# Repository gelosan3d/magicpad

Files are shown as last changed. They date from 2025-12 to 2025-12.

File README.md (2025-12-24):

# Angelos' MagicPad

### Renders + Workplace Screenshots 
Fusion_Case_Pretty
Case_Pretty_1


---

### Inspiration: 
I got my main inspiration from existing streaming decks and macropads such as the Elgado Streakdeck. I really liked the customisability but always though that the buttons were very tacky when pressed and I didn't particularly like the lack of a knob in some models

### BOM:
- 1x XIAO RP2040
- 2x SK6812MINI-E LED's 
- 2x EC11 Rotary Encoders
- 8x Cherry MX Footprint Switches
- 1x 0.91" OLED Panel
- 1x [MCP23017 IO Expander](https://item.taobao.com/item.htm?id=873700756247) (TaoBao Link)
- 3x [4.7kΩ Resistors](https://detail.tmall.com/item.htm?id=855810249338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) (TMall Link) 
- 4x [m3 5W4D Heat-set Inserts](https://www.aliexpress.us/item/2255800046543591.html)
- 4x m3x16mm Screws

#### 3D Print:
  - Top_Case.stl
  - Bottom_Case.stl

Schematic            |  PCB         |   Case
:-------------------------:|:-------------------------:|:-------------------------:|
  |   | 

### Licensing
This project falls under the MIT License (see LICENSE.md), which I chose because of how much I used all the amazing community projects and help (a ***lot*** with the code) and the support from the overall open-source community. 

This has inspired and made me want to leave my work as open source, hopefully inspiring or helping someone else in the future! 

--- 

### Thanks!!!
Many many many thanks to everyone at the Hackclub team and AMD for making this work, really amazing help and support to the whole community!

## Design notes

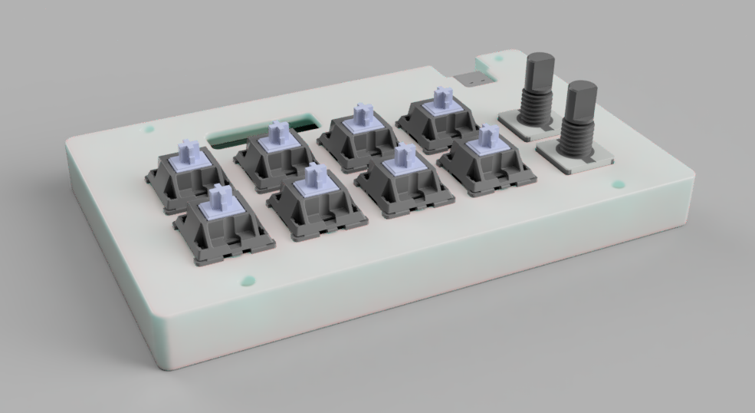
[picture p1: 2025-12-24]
CAD/Case_Pretty_1.png

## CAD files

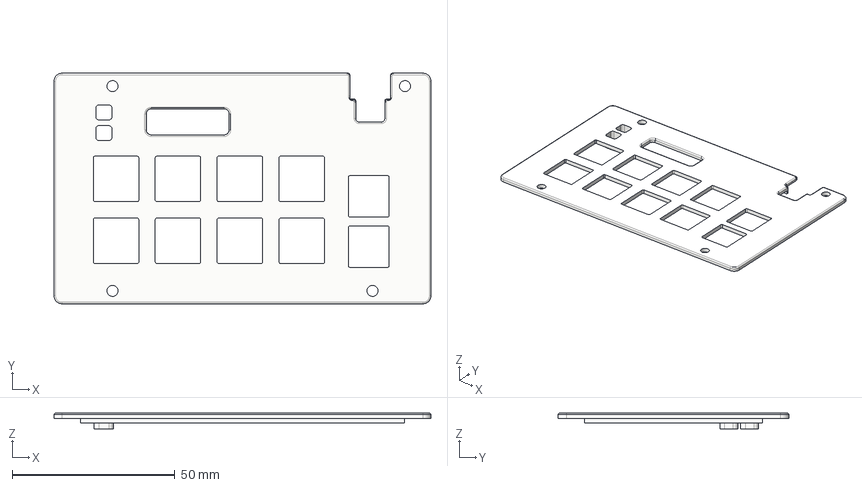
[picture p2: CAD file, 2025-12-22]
CAD/Case_Top.step
116.0 x 71.0 x 4.90 mm

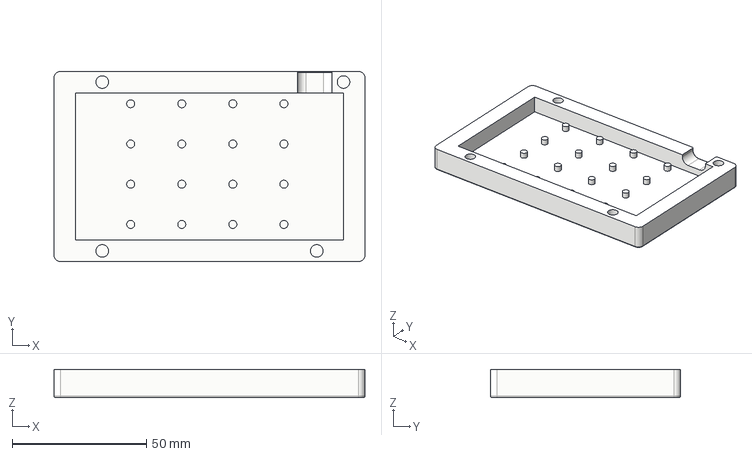
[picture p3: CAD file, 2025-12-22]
CAD/Case_Bottom.step
116.0 x 71.0 x 10.5 mm

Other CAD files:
CAD/Case_v1_Case_Bottom.f3d
CAD/Case_v1_Case_Top.f3d
CAD/Extras/Cherry_MX_Switch.f3d
CAD/Extras/LED SK6812MINI-E.f3d
CAD/Extras/Rotary_Encoder.f3d
CAD/Extras/Seeed Studio XIAO RP2040.f3d
CAD/PCB_v3.f3d

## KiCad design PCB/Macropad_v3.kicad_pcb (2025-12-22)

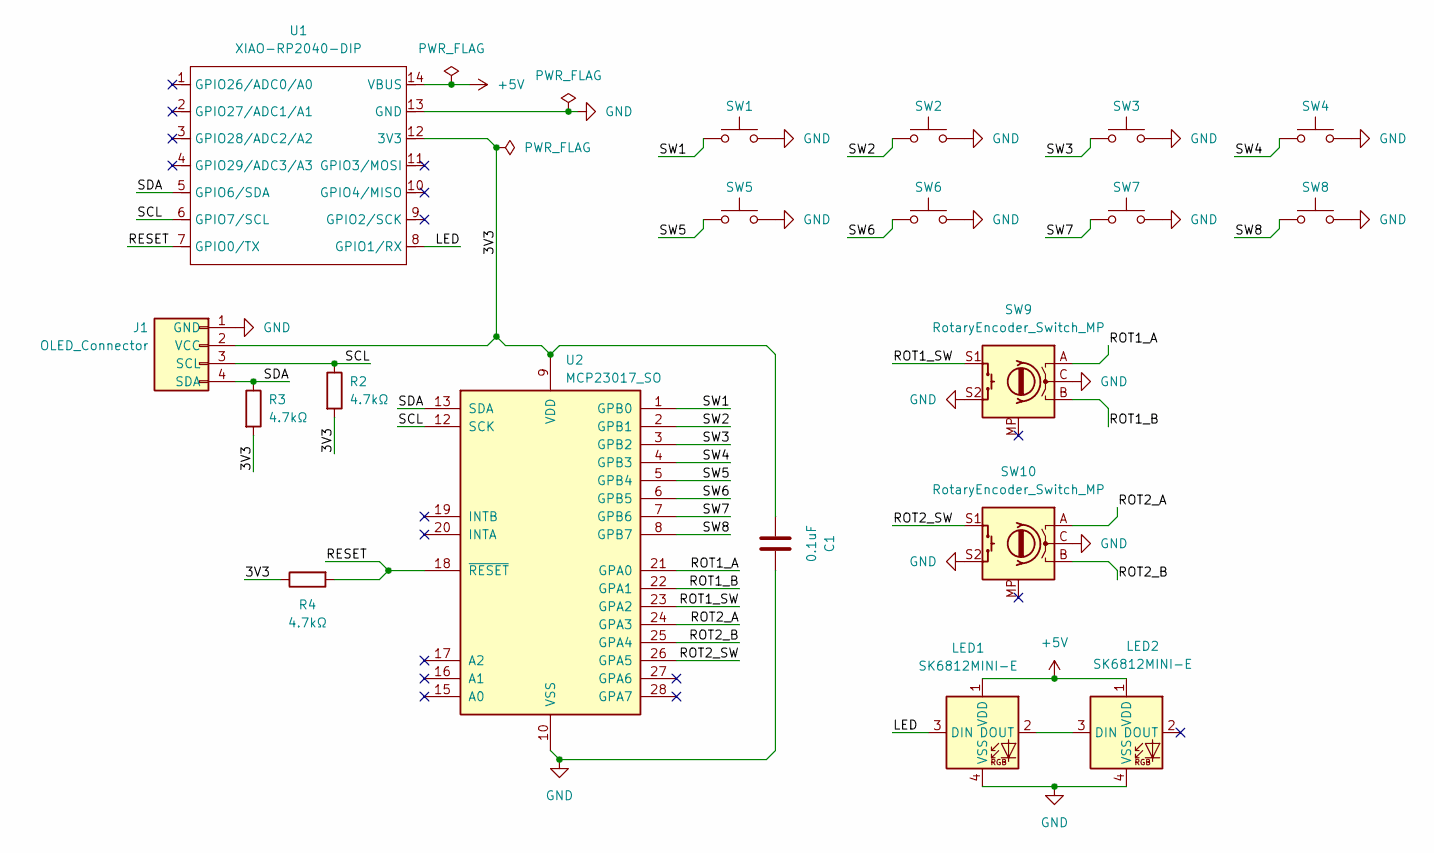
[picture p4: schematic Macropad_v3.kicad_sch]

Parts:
C1: 0.1uF; C_0603_1608Metric_Pad1.08x0.95mm_HandSolder
J1: OLED_Connector; SSD1306-0.91-OLED-4pin-128x32
LED1, LED2: SK6812MINI-E; LED_6028R
R2, R3, R4: 4.7kΩ; R_0603_1608Metric_Pad0.98x0.95mm_HandSolder
SW1, SW2, SW3, SW4, SW5, SW6, SW7, SW8: SW_Push; SW_Cherry_MX_1.00u_PCB
SW9, SW10: RotaryEncoder_Switch_MP; RotaryEncoder_Alps_EC11E-Switch_Vertical_H20mm_CircularMoun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
U1: XIAO-RP2040-DIP
U2: MCP23017_SO; SOIC-28W_7.5x17.9mm_P1.27mm

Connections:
+5V: LED1.1 (VDD), LED2.1 (VDD), U1.14 (VBUS)
/3V3: C1.1, J1.2 (VCC), R2.2, R3.2, R4.1, U1.12 (3V3), U2.9 (VDD)
/LED: LED1.3 (DIN), U1.8 (GPIO1/RX)
/RESET: R4.2, U1.7 (GPIO0/TX), U2.18 (~RESET)
/ROT1_A: SW9.A, U2.21 (GPA0)
/ROT1_B: SW9.B, U2.22 (GPA1)
/ROT1_SW: SW9.S1, U2.23 (GPA2)
/ROT2_A: SW10.A, U2.24 (GPA3)
/ROT2_B: SW10.B, U2.25 (GPA4)
/ROT2_SW: SW10.S1, U2.26 (GPA5)
/SCL: J1.3 (SCL), R2.1, U1.6 (GPIO7/SCL), U2.12 (SCK)
/SDA: J1.4 (SDA), R3.1, U1.5 (GPIO6/SDA), U2.13 (SDA)
/SW1: SW1.1, U2.1 (GPB0)
/SW2: SW2.1, U2.2 (GPB1)
/SW3: SW3.1, U2.3 (GPB2)
/SW4: SW4.1, U2.4 (GPB3)
/SW5: SW5.1, U2.5 (GPB4)
/SW6: SW6.1, U2.6 (GPB5)
/SW7: SW7.1, U2.7 (GPB6)
/SW8: SW8.1, U2.8 (GPB7)
GND: C1.2, J1.1 (GND), LED1.4 (VSS), LED2.4 (VSS), SW1.2, SW2.2, SW3.2, SW4.2, SW5.2, SW6.2, SW7.2, SW8.2, SW9.C, SW9.S2, SW10.C, SW10.S2, U1.13 (GND), U2.10 (VSS)
unnamed: LED1.2 (DOUT), LED2.3 (DIN)

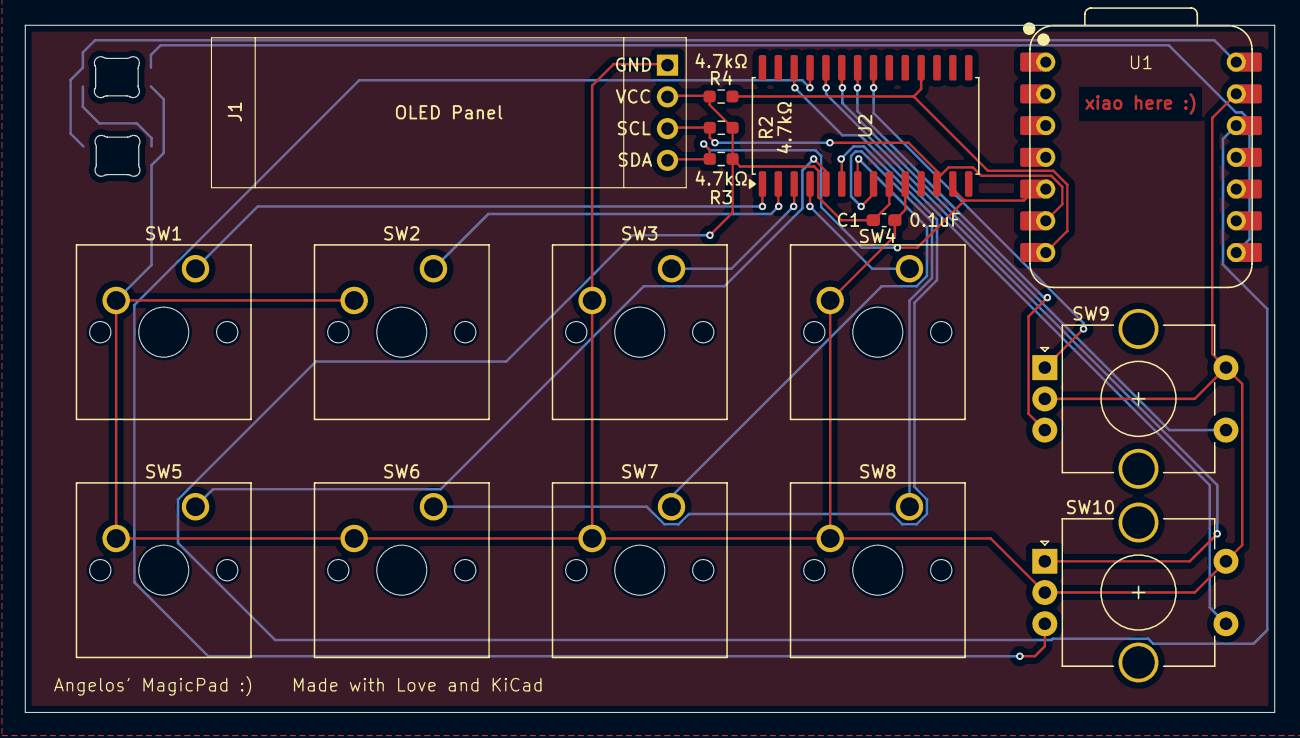
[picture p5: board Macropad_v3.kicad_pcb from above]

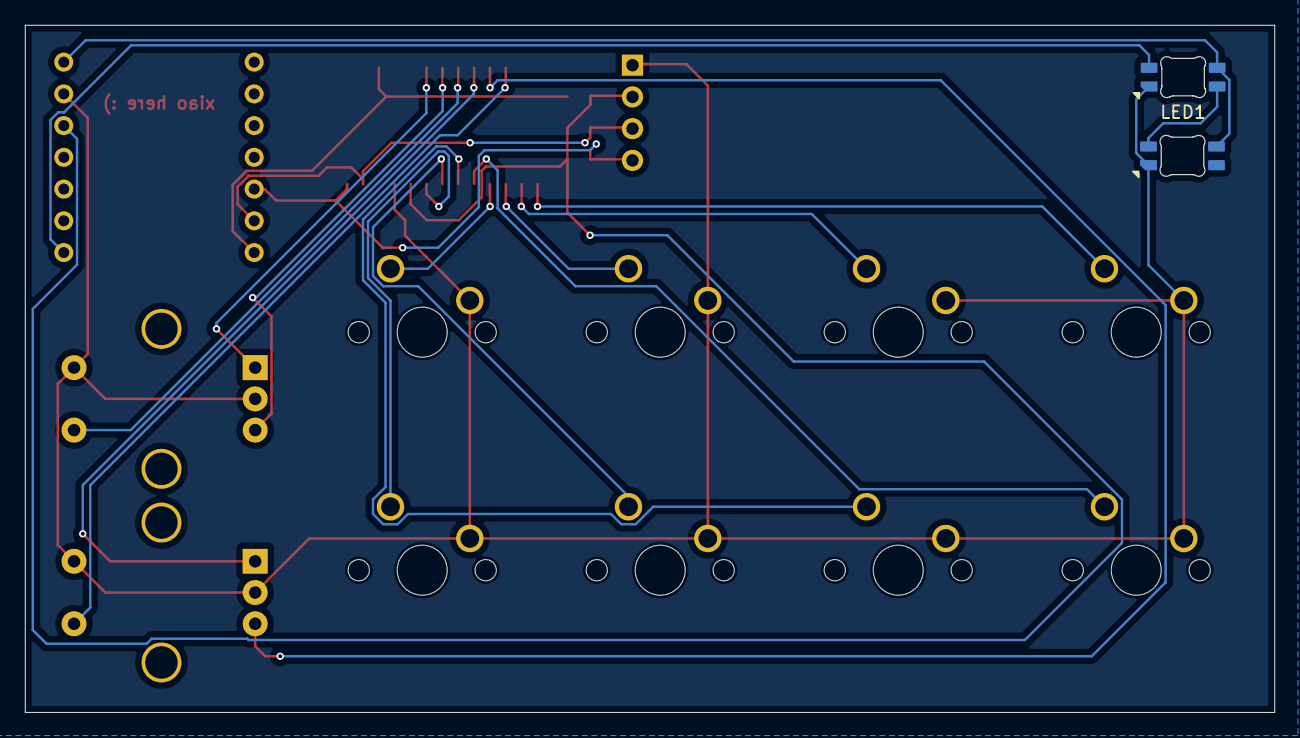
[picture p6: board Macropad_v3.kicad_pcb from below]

Board: 2 copper layers, 100.0 x 55.0 mm, 19 parts (2 on the bottom side), 22 nets.

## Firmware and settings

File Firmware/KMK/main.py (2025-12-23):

print("Starting macropad firmware")

from kmk_firmware.kmk.kmk_keyboard import KMKKeyboard
from board.pins import oled
from kmk_firmware.kmk.modules.layers import Layers
from kmk_firmware.kmk.keys import KC
keyboard = KMKKeyboard()

layers = Layers()
keyboard.modules.append(layers)
NUM_LAYERS = 8  # define number of layers, 8 is max allowed 

current_layer = 0
def encoder_layer_cycle(direction):
    global current_layer
    if direction > 0:
        current_layer = (current_layer + 1) % NUM_LAYERS
    else:
        current_layer = (current_layer - 1) % NUM_LAYERS
    keyboard.active_layers = [current_layer]


from board.pins import (
    DIRECT_PINS,
    ENC1_A, ENC1_B,
    ENC2_A, ENC2_B,
    LED_DATA,
)

from kmk_firmware.kmk.scanners import DirectPins
keyboard.matrix = DirectPins (
    pins = DIRECT_PINS,
    value_when_pressed = False
)

from kmk_firmware.kmk.modules.encoders import EncoderHandler
encoder = EncoderHandler()
encoder.pins = (
    (ENC1_A, ENC1_B),
    (ENC2_A, ENC2_B),
)
encoder.map = [
    (
        lambda: encoder_layer_cycle(-1),    # CCW
        lambda: encoder_layer_cycle(+1),    # CW
        KC.NO,                              # press
    ), 
    (
        KC.NO,                              # CCW / placeholder
        KC.NO,                              # CW / placeholder
        KC.NO,                              # press / placeholder
    )
]
keyboard.modules.append(encoder)

from kmk_firmware.kmk.extensions.rgb import RGB
rgb = RGB(
    pixel_pin = LED_DATA,
    num_pixels = 2, 
    hue_default = 0,
    sat_default = 255,
    val_default = 64,
    animation_speed = 1,
)
keyboard.extensions.append(rgb)

keyboard.keymap = [
    # layer 0
    [
        KC.NO,    # K_1
        KC.NO,    # K_2
        KC.NO,    # K_3
        KC.NO,    # K_4
        KC.NO,    # ENC1 switch
        KC.NO,    # K_5
        KC.NO,    # K_6
        KC.NO,    # K_7
        KC.NO,    # K_8
        KC.NO,    # ENC2 switch
    ],
    # War Thunder
    [
        KC.NO,    # K_1
        KC.NO,    # K_2
        KC.NO,    # K_3
        KC.NO,    # K_4
        KC.NO,    # ENC1 switch
        KC.NO,    # K_5
        KC.NO,    # K_6
        KC.NO,    # K_7
        KC.NO,    # K_8
        KC.NO,    # ENC2 switch
    ],
    # layer 2
    [
        KC.NO,    # K_1
        KC.NO,    # K_2
        KC.NO,    # K_3
        KC.NO,    # K_4
        KC.NO,    # ENC1 switch
        KC.NO,    # K_5
        KC.NO,    # K_6
        KC.NO,    # K_7
        KC.NO,    # K_8
        KC.NO,    # ENC2 switch
    ]
]

"""
KC.LCTRL(KC.C)      # Ctrl+C
KC.LSHIFT(KC.A)     # Shift+A
KC.LALT(KC.TAB)     # Alt+Tab
"""
def update_oled():
    oled.fill(0)
    oled.text(str(current_layer), 0, 12, 1)
    oled.show()

"""
def before_scan():
    update_oled()

keyboard.before_matrix_scan = before_scan
"""

oled.fill(0)
oled.show()

keyboard.go()

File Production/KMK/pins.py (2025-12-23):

# firmware/board/pins.py
# imports pins for both XIAO and MCP23017
import board
import busio
from kmk_firmware.kmk.extensions.ioexpander import MCP23017
from kmk_firmware.kmk.extensions.display.ssd1306 import ssd1306

i2c = busio.I2C(board.SCL, board.SDA)       # I2C bus (XIAO default pins)
expander = MCP23017(i2c, address=0x20)      # MCP23017 at address 0x20
    
# OLED display
oled = SSD1306_I2C(
    128, 
    32, 
    i2c, 
    addr=0x3C
)

"""
K_<number>      - keys
ENC<n>_<signal> - encoders
LED_<name>      - LEDs 
"""

# reset
SYS_RESET = board.GP0 # reset pin

# keys
K_1 = expander.get_pin(8)    # SW1
K_2 = expander.get_pin(9)    # SW2
K_3 = expander.get_pin(10)   # SW3
K_4 = expander.get_pin(11)   # SW4
K_5 = expander.get_pin(12)   # SW5
K_6 = expander.get_pin(13)   # SW6
K_7 = expander.get_pin(14)   # SW7
K_8 = expander.get_pin(15)   # SW8

# encoder
ENC1_A  = expander.get_pin(0)   # ROT1_A
ENC1_B  = expander.get_pin(1)   # ROT1_B
ENC1_SW = expander.get_pin(2)   # ROT1_SW

ENC2_A  = expander.get_pin(3)   # ROT2_A
ENC2_B  = expander.get_pin(4)   # ROT2_B
ENC2_SW = expander.get_pin(5)   # ROT2_SW

"""
from pins import (
    DIRECT_PINS,
    ENC1_A, ENC1_B,
    ENC2_A, ENC2_B,
    LED_DATA,
)"""

ENCODER_PINS = (
    (ENC1_A, ENC1_B),
    (ENC2_A, ENC2_B),
)

DIRECT_PINS = (
    K_1, 
    K_2, 
    K_3, 
    K_4, 
    ENC1_SW,
    K_5, 
    K_6, 
    K_7, 
    K_8, 
    ENC2_SW
)

# LEDs
LED_DATA = board.GP1 # SK6812 MINI

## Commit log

2025-12-22 v1 uploads
    added basic files, still missing files for KMK Firmware, README, LISCENCE, and .gitignore
    [Case_Bottom.step, Case_Top.step, Case_v1_Case_Bottom.f3d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]
2025-12-24 updated README.md
    added screenshot of case without electronics
